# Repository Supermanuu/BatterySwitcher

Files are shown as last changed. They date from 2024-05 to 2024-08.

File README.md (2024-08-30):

# Sofle Battery Switcher




We are triying to make a battery switch for the Sofle Keyboard, or properly said, the [nRFMicro](https://github.com/joric/nrfmicro/tree/1.4) or Pro Micro compatible board used by the [Sofle](https://github.com/josefadamcik/SofleKeyboard) Keyboard.

Our goal is to have a PCB that could short and open the baterry supply via a switch, keeping as low profile as possible and doing it as integrated as possible. Also, the device should change the battery in any of the positions, because the `nRFMicro` has a battery charge monitor.

## Setup

In order to use this repo you should add a `KICAD_3RD_PARTY` variable with `${KIPRJMOD}/3rdparty/` value. If you had installed Kicad for all users, the variable shall be a system variable. Otherwise it can be a user variable.

Also, to commit the messages we use <https://github.com/marketplace/actions/github-actions-create-tag>, so your commit messages need to follow a certain format. In order to do so, you need to install some git hooks. You can do that by running the following command:

```bash
./scripts/setup-hooks.sh
```

## Used plugins

* For download parts from [Component Search Engine](https://componentsearchengine.com/): [Import-LIB-KiCad-Plugin](https://github.com/Steffen-W/Import-LIB-KiCad-Plugin)

## Documentation

See [the documentation](doc/user-guide.md).

## Releases

See [Github releases](https://github.com/Supermanuu/BatterySwitcher/releases).

Each release has:

* User guide in `user-guide.html`, with a lot of information to build the PCB.
* iBOM in `ibom.html`, with all the PCB parts.
* Another BOM in `out-of-bom.html`, with parts not used by the PCB, but needed in some cases.
* Schematic in `schematic.pdf`, with the diagram of the PCB.
* PCB images:
  * top view in `top.png`.
  * bottom view in `bottom.png`.

Another attach has:

* Gerber files and drill files in `manufacturing.zip`
* 3D model in `3D.step`

## Generate release

To generate a release you will need to create a new `release/*` branch and make a PR from that branch to main. In that scenario, when the PR is closed a job will be launched. That job will generate a tag and a release with all the change information from the previous tag until now, using the commit contents as specified in <https://github.com/marketplace/actions/github-tag>.

### Release changelog management

In order to auto-generate the changelog, the commits shall use this rules:

| Keyword | Example | Increases |
|---|---|---|
| `fix(something)`  | fix(pencil): stop graphite breaking when too much pressure applied | Patch |
| `feat(something)` | feat(pencil): add 'graphiteWidth' option | Minor |
| `perf(something)` | perf(pencil): remove graphiteWidth option | Major |

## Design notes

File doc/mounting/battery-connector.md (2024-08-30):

# Other components

This build needs a battery connector only if you have soldered the optional J1 connector only.

The materials that you  will need apart of  the BOM are described [here](../out-of-bom.md).

To mount the battery connector you should cut the wires at the appropiate length and crimp a cable terminator. First crimp the black cable:

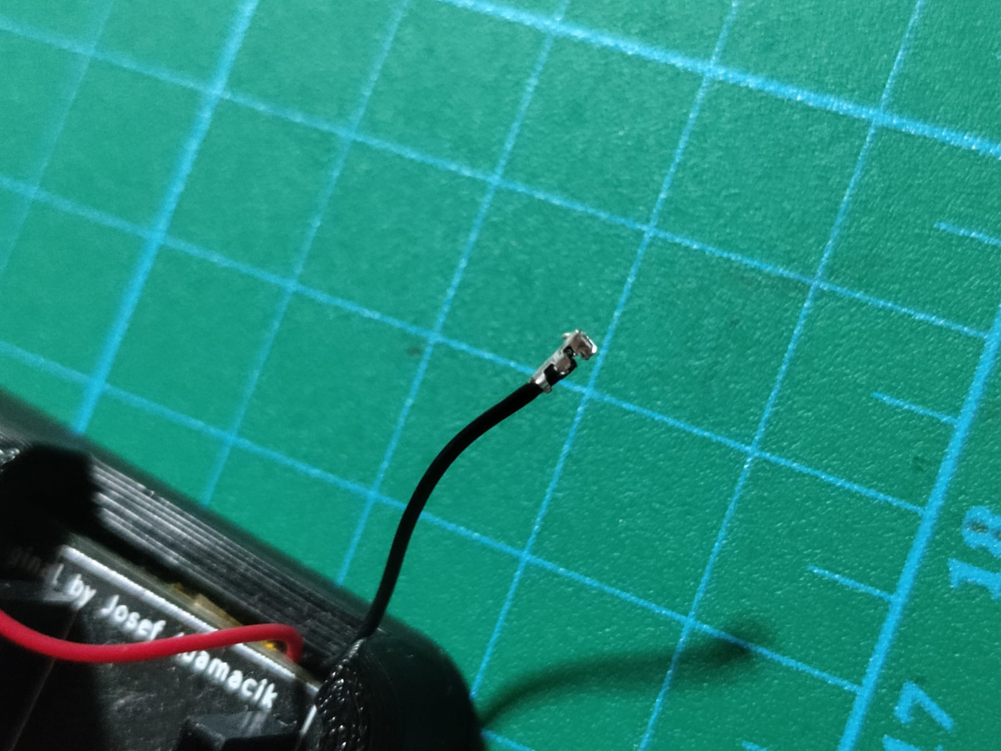
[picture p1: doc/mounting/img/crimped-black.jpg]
Black crimped


Then you should insert the terminator into the connector housing:

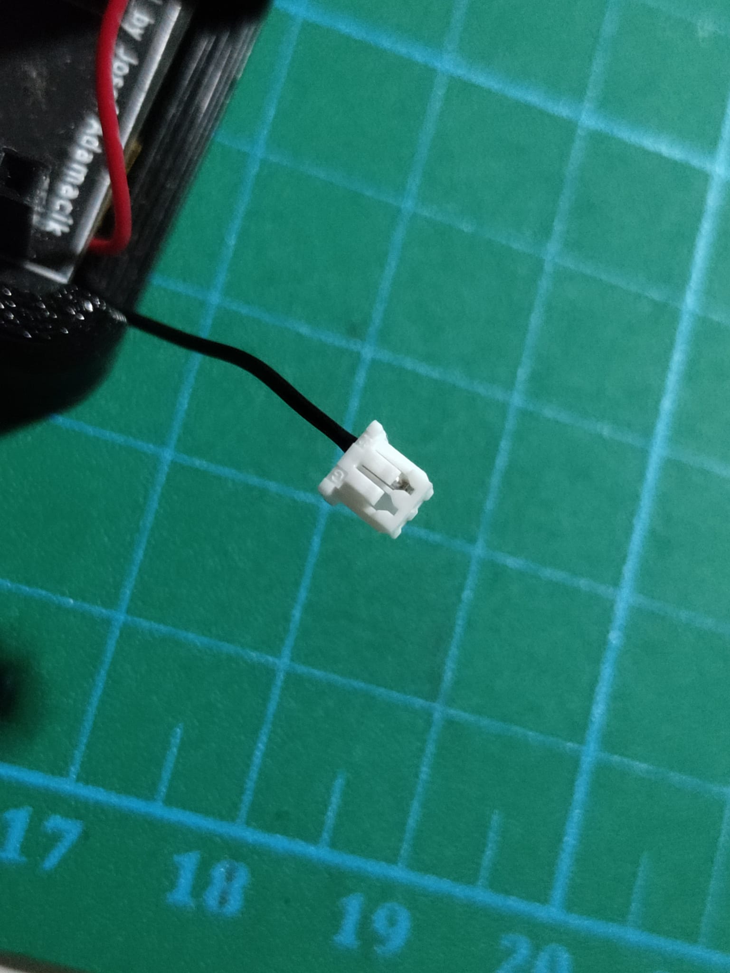
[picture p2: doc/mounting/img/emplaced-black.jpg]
Black emplaced


Now do it with the red wire:

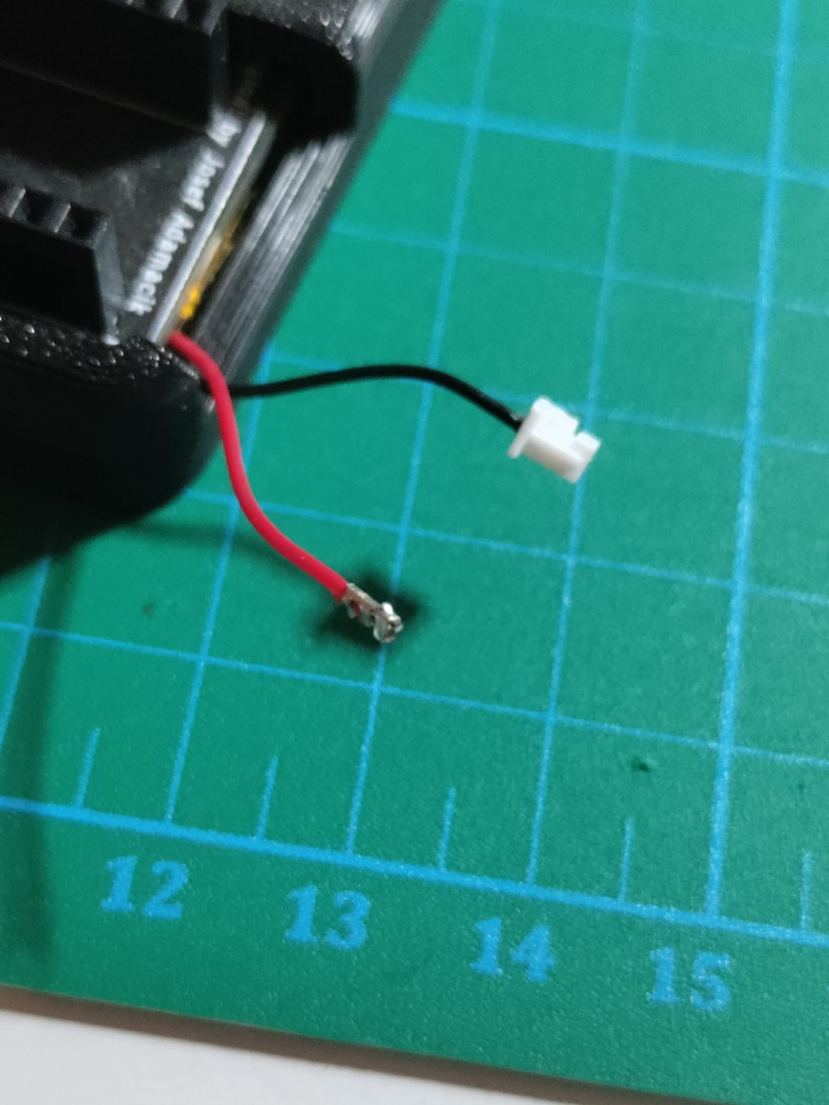
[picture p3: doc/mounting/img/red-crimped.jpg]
Red crimped


And add it to the connector:

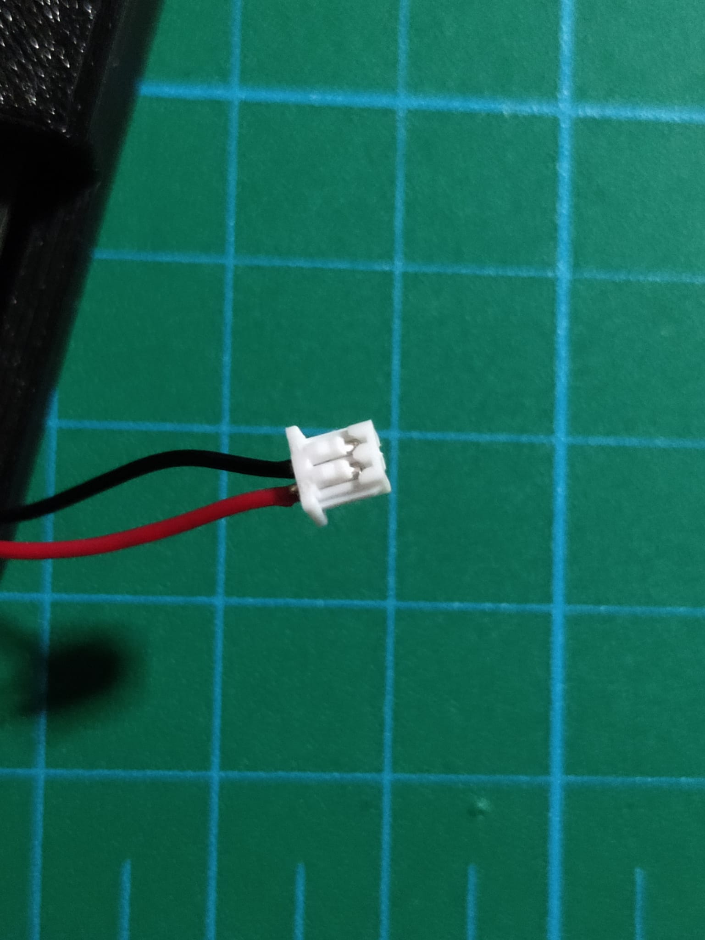
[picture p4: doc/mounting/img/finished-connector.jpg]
Finished connector


Finally you have your battery connector ready!

You can continue with the [PCB](./pcb.md).

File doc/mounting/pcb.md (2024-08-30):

# Mounting the PCB

Get the PCB and the D1:

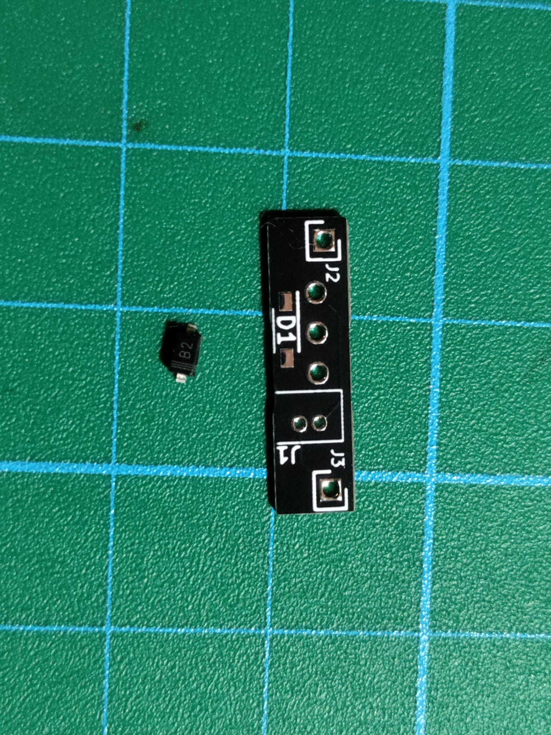
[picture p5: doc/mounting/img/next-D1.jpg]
D1


Solder the D1 component. Place the PCB on the bottom view and solder the diode paths with caution. Check the diode polarity:

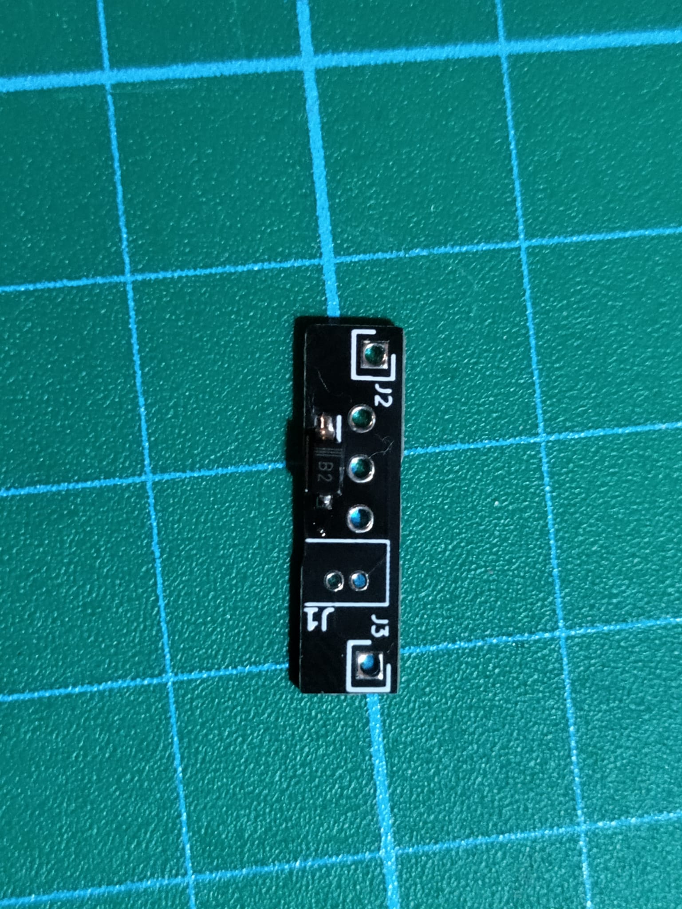
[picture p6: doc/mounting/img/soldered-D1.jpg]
Soldered D1


Get the J1 component (optional):

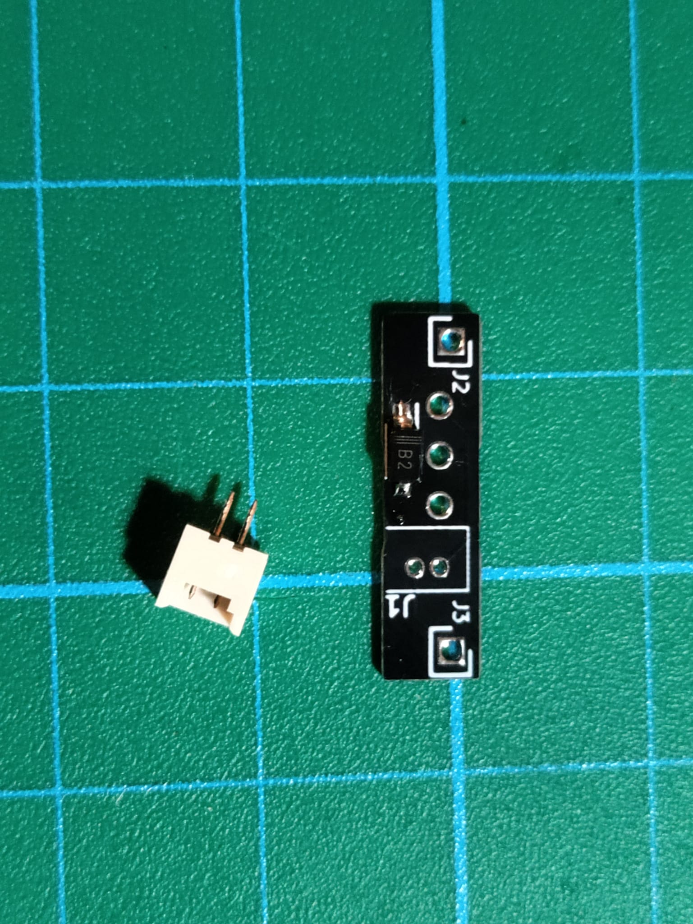
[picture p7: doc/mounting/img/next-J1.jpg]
J1


Solder the J1 component (optional). From the bottom view, solder the connector. Use tape for secure and effective placement. Place the connetor fixing plate inwards:

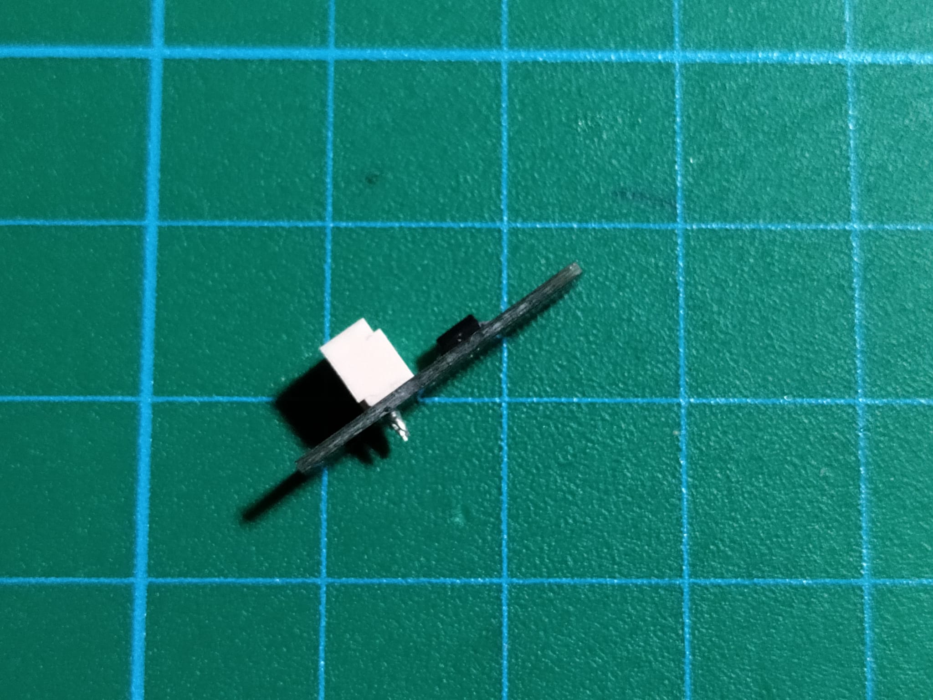
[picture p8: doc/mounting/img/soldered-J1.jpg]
Soldered J1


Get the S1 component:

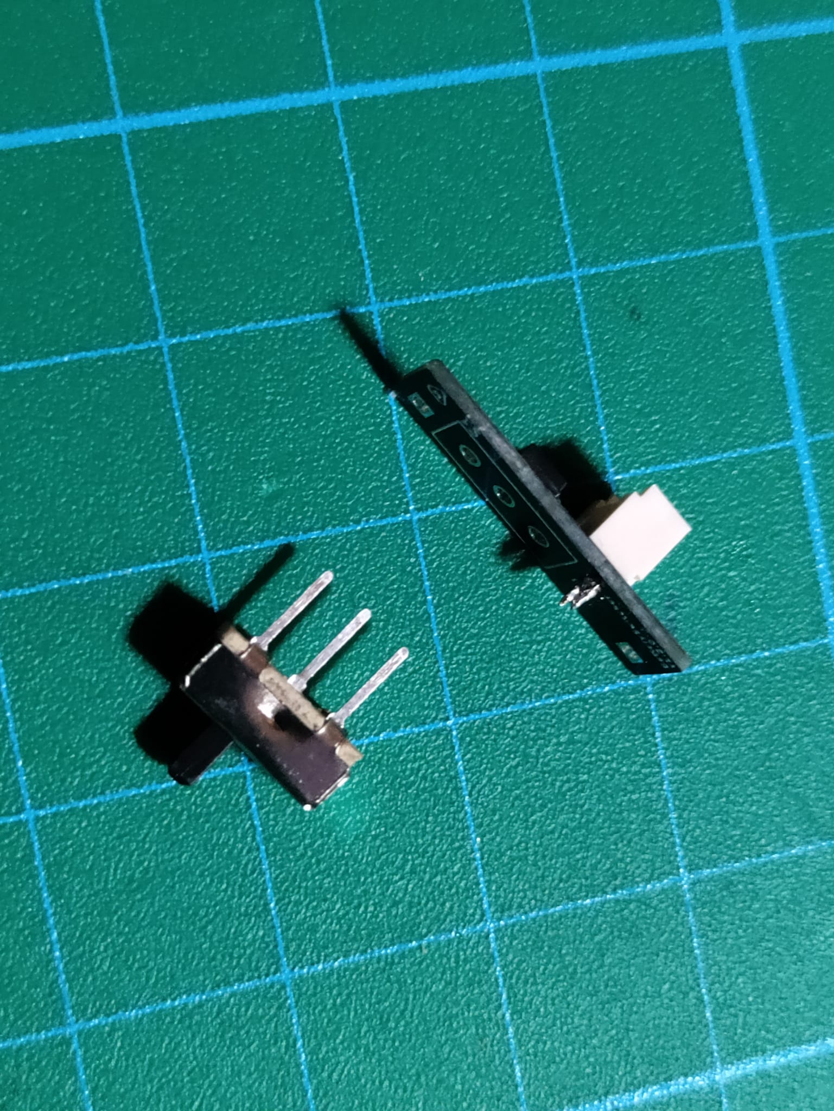
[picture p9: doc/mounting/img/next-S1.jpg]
S1


Solder the S1 component. Just solder the three pins using tape.

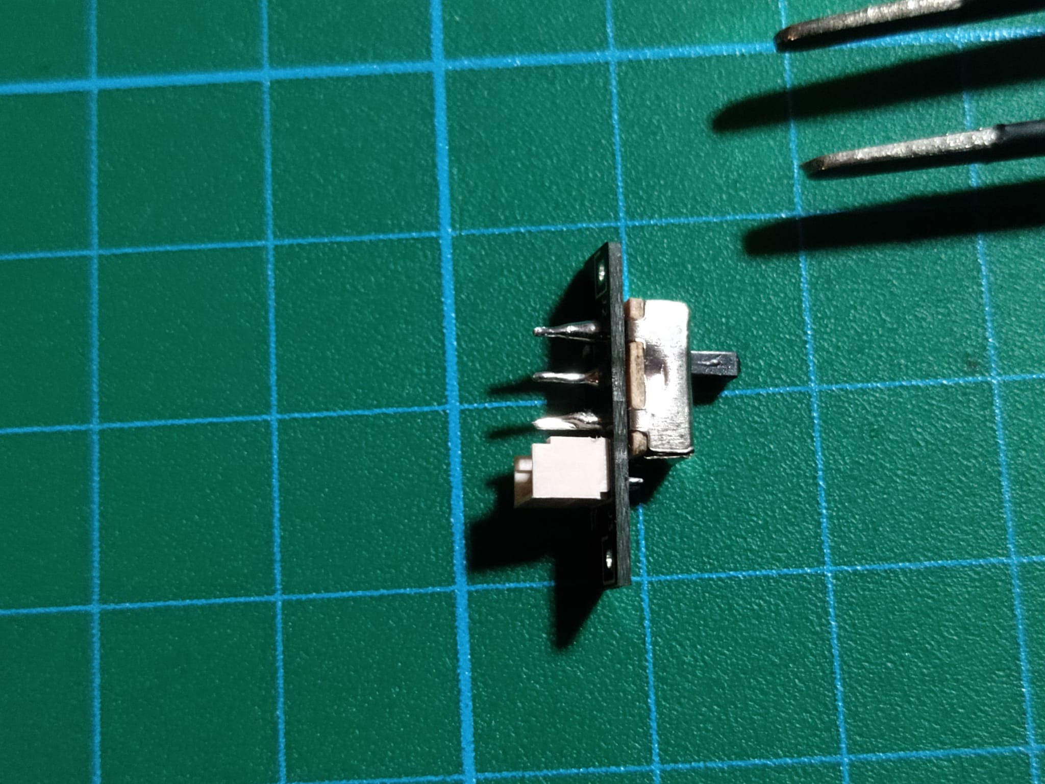
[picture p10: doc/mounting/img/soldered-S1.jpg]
Soldered S1


At this point, perform some excess trimming to avoid future problems:

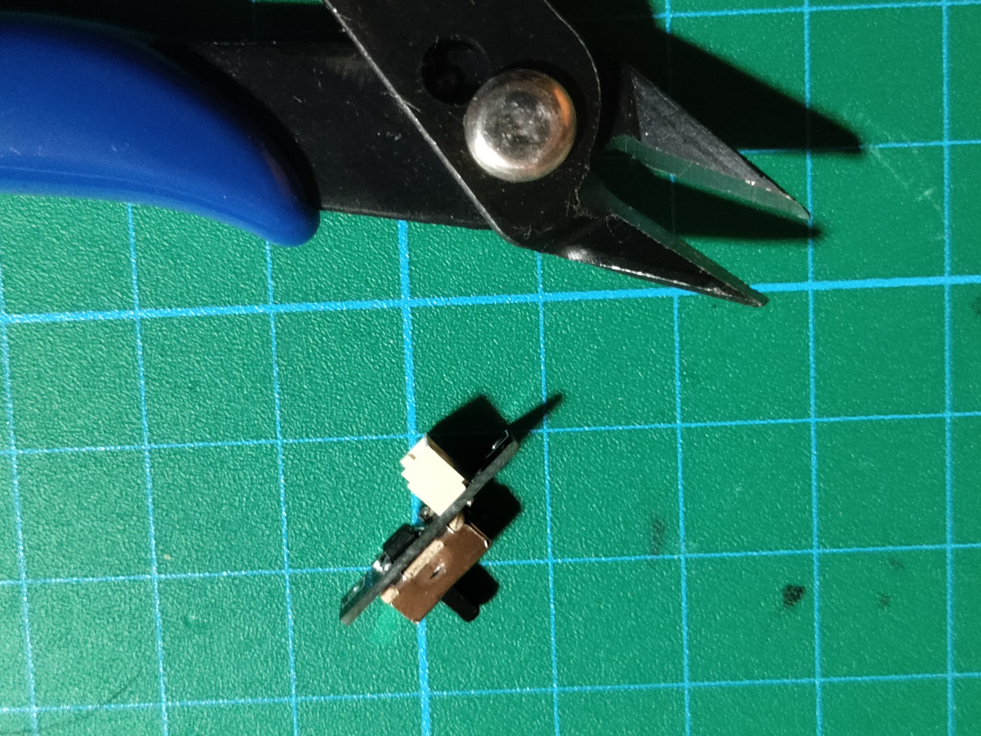
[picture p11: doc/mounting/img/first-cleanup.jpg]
Trim some excess


Follow the [battery connector](battery-connector.md) section if you have soldered the battery connector.

At this point you need to bend the PCB headers in a right angle. Split the headers and remove the retainer:

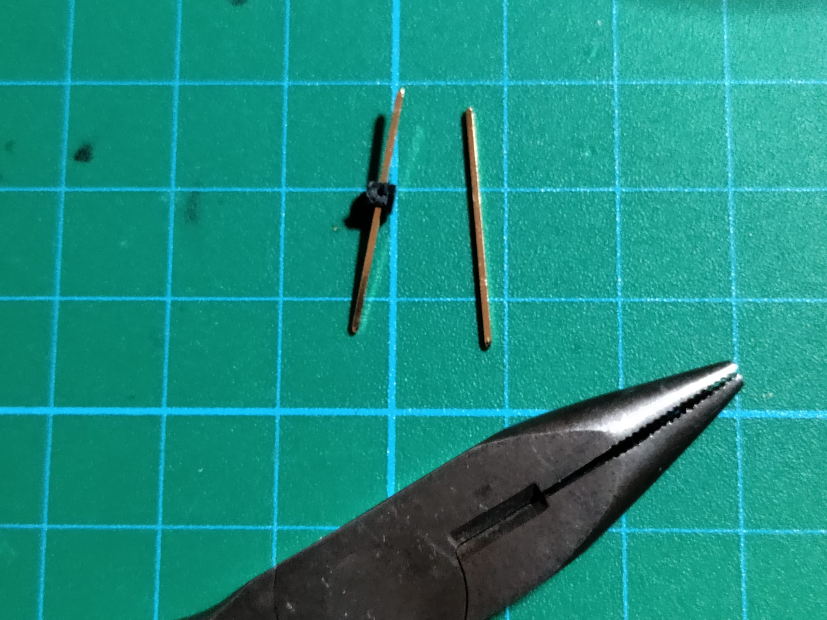
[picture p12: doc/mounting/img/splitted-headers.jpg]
Splitted headers


Then do a 90 degree bend:

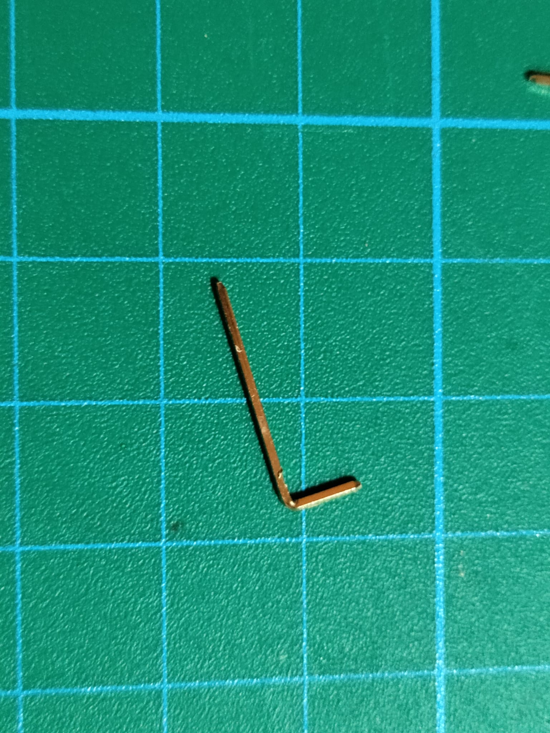
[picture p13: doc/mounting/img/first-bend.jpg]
First 90 degree angle


Then perform a 30 degree angle and another -30 degree angle:

TODO: add image

**IMPORTANT: If you want to avoid rising the switch from the keyboard base, you should not perform only 90 degree angles, try to use the minimum slope in 2nd and 3th bends. Avoid the following shape:**

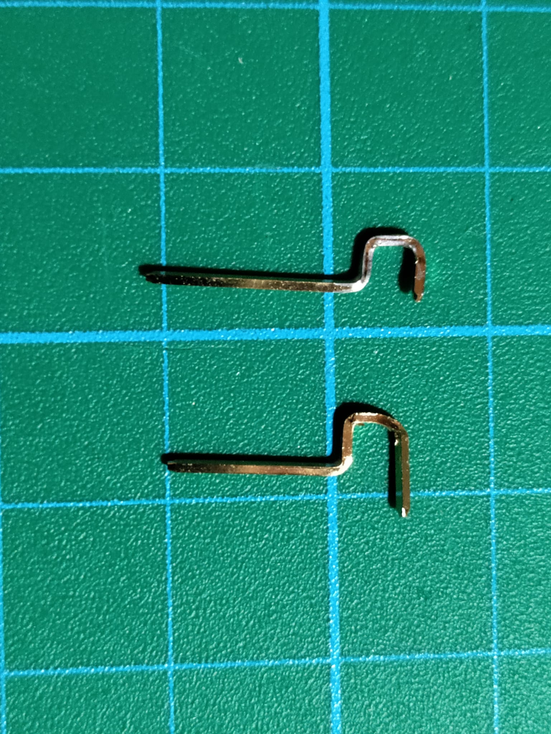
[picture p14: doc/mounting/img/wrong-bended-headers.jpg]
Wrong bending


That will be the ending shape. You will need two of the previous bended headers to be soldered into J2 and J3. First solder J2:

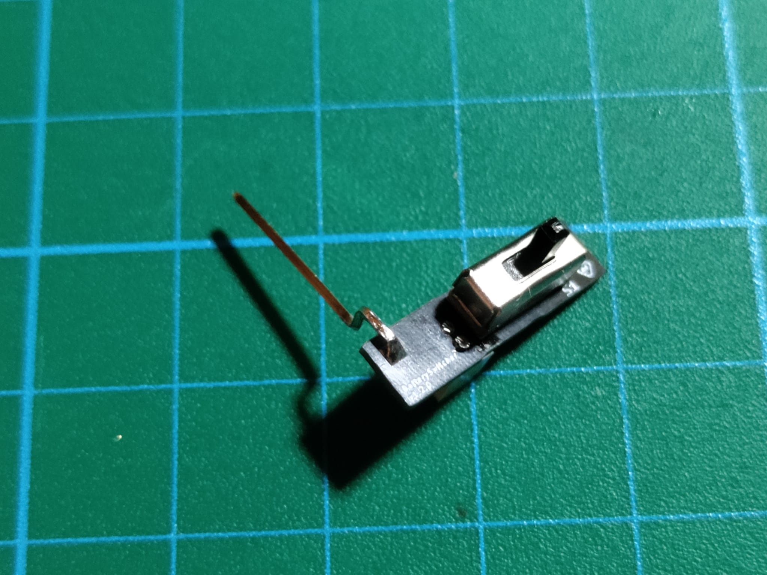
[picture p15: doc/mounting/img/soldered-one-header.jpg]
Soldered J2


Then solder J3. It will be better to solder it with the tob view at the top:

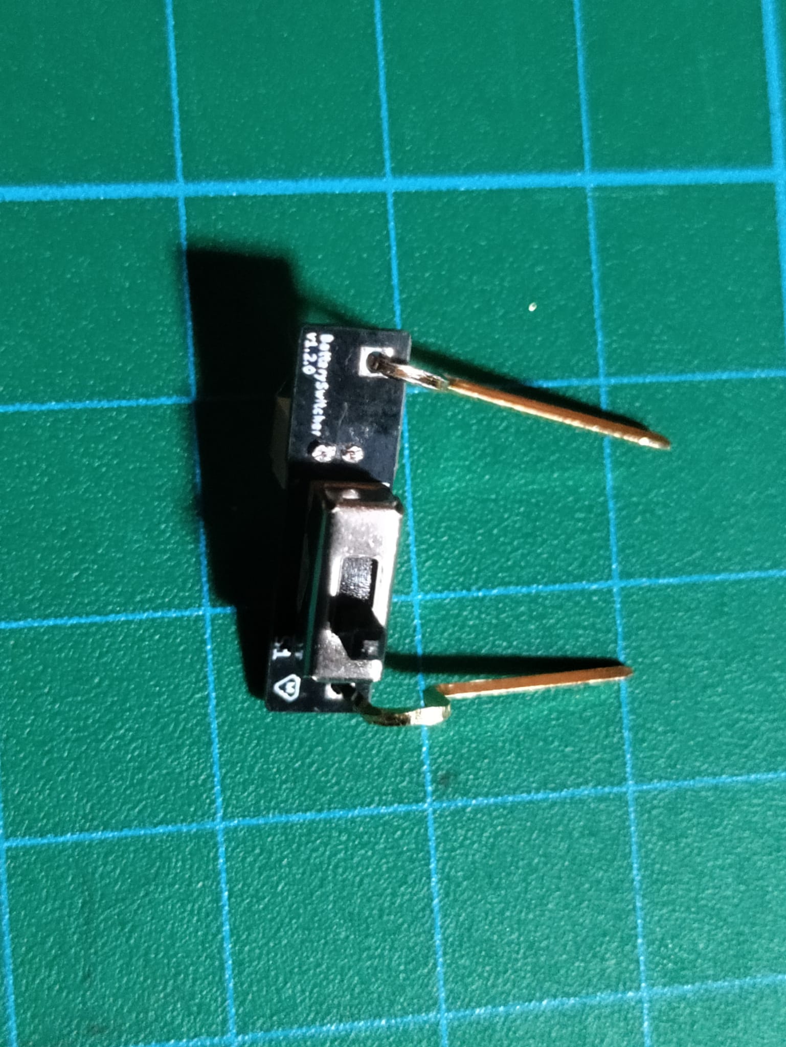
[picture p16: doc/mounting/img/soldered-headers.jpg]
Soldered J3

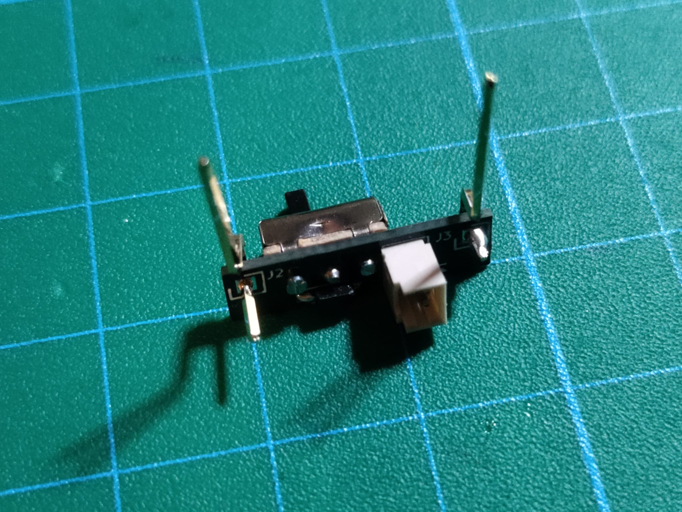
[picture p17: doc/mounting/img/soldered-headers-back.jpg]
Soldered J3 back view


Trim again the excess material:

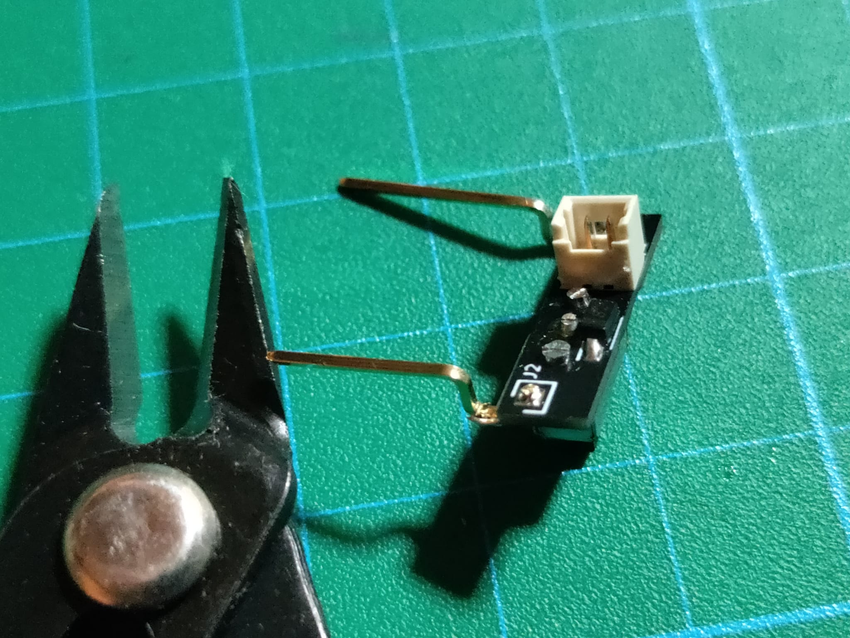
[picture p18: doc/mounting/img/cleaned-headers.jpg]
Second trimming


At this point you can solder it to the Pro Micro or compatible board:

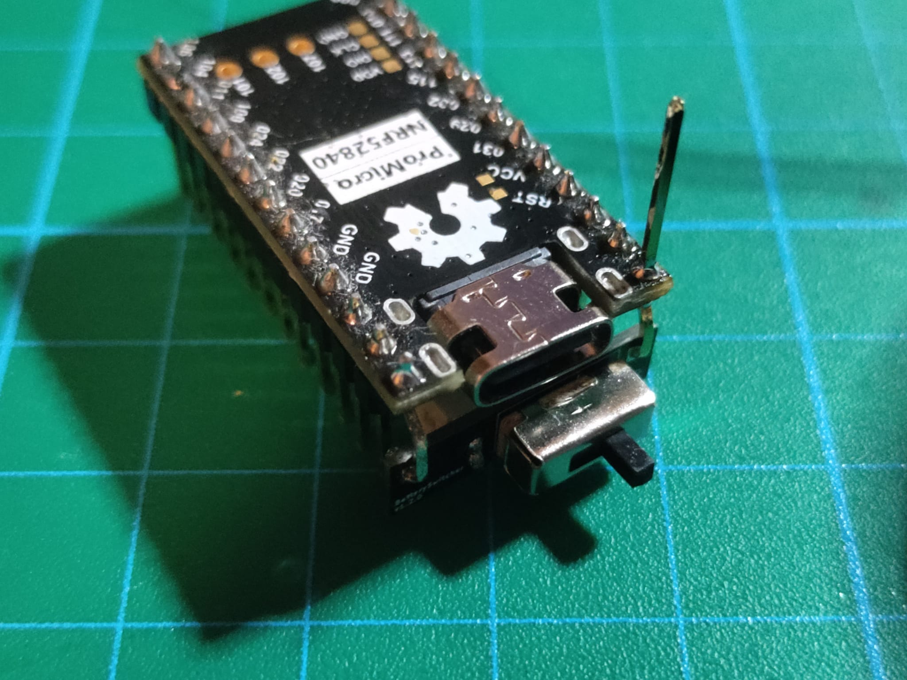
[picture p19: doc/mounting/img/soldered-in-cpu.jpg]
Soldered in CPU

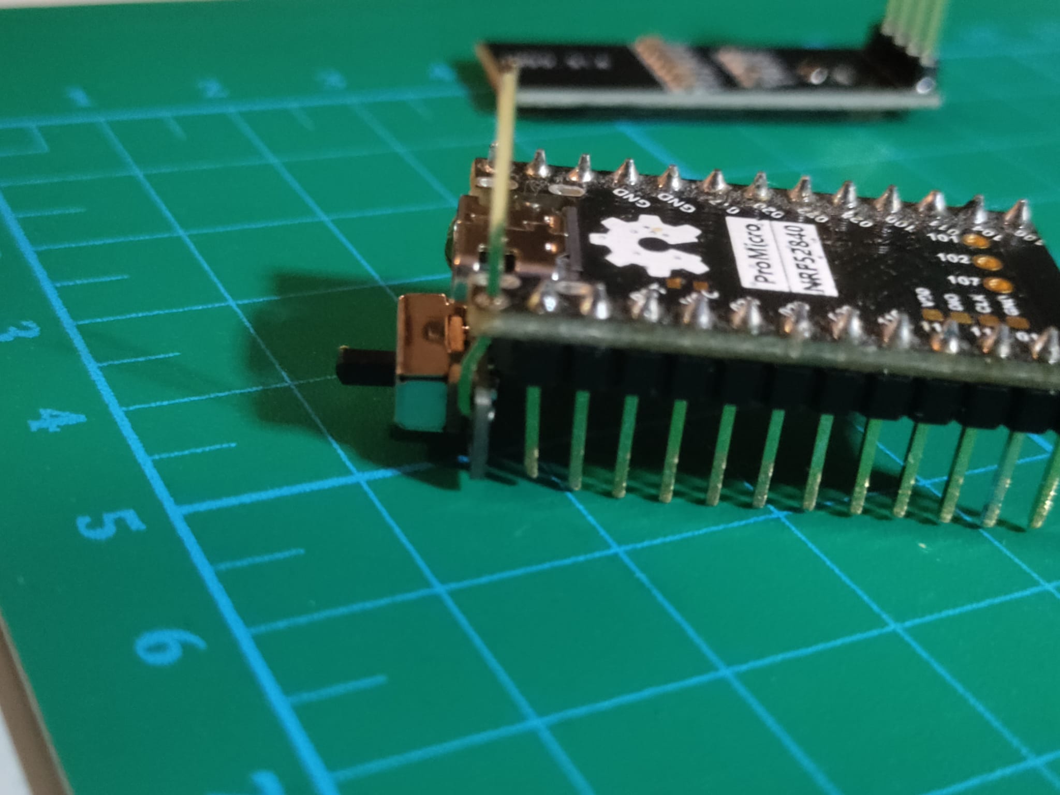
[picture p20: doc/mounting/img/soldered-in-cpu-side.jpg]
Soldered in CPU side


**IMPORTANT: Try to avoid to move the headers when are soldered because you can break a header, as it happened to me:**

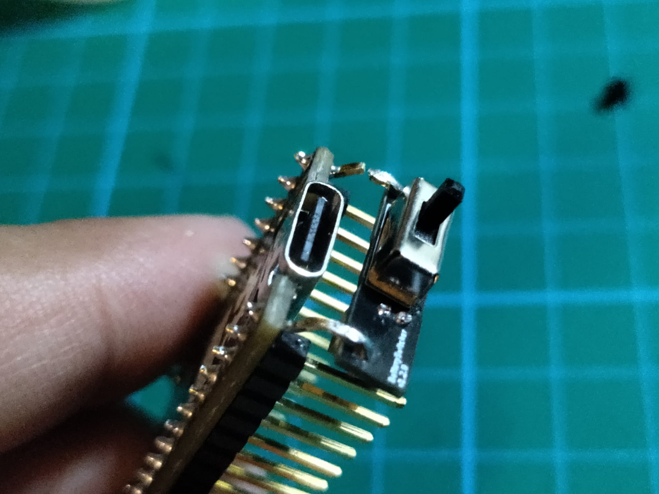
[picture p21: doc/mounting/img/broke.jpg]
Broken header


Remove again the excess and start mounting altogheder!

1. Connect the battery connector
2. Connect the Pro Micro compatible CPU to the keyboard
3. Connect the OLED displayy, if you have it.

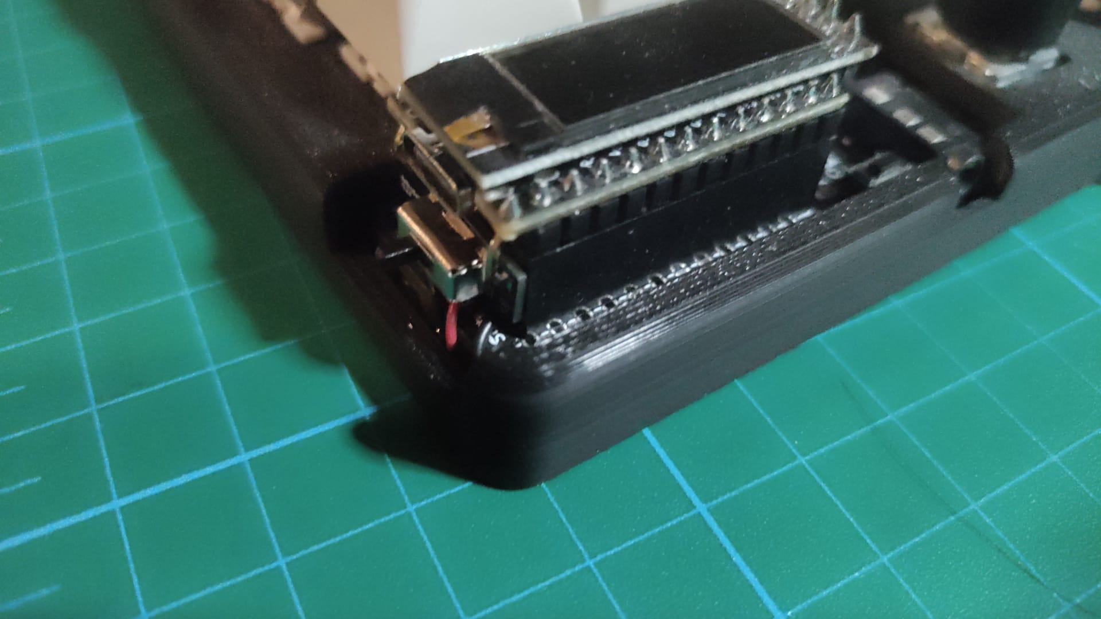
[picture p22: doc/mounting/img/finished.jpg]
Finished


Done!

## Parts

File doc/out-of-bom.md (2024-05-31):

# Non PCB parts

|#  |Qty|P/N |Purpose | Link |
|---|---|---|---|---|
| 1 | 2 | 50079-8001 | Battery connector | [Molex](https://www.molex.com/en-us/products/part-detail/500798001) |
| 2 | 1 | 51021-0200 | Battery connector | [Molex](https://www.molex.com/en-us/products/part-detail/510210200) |

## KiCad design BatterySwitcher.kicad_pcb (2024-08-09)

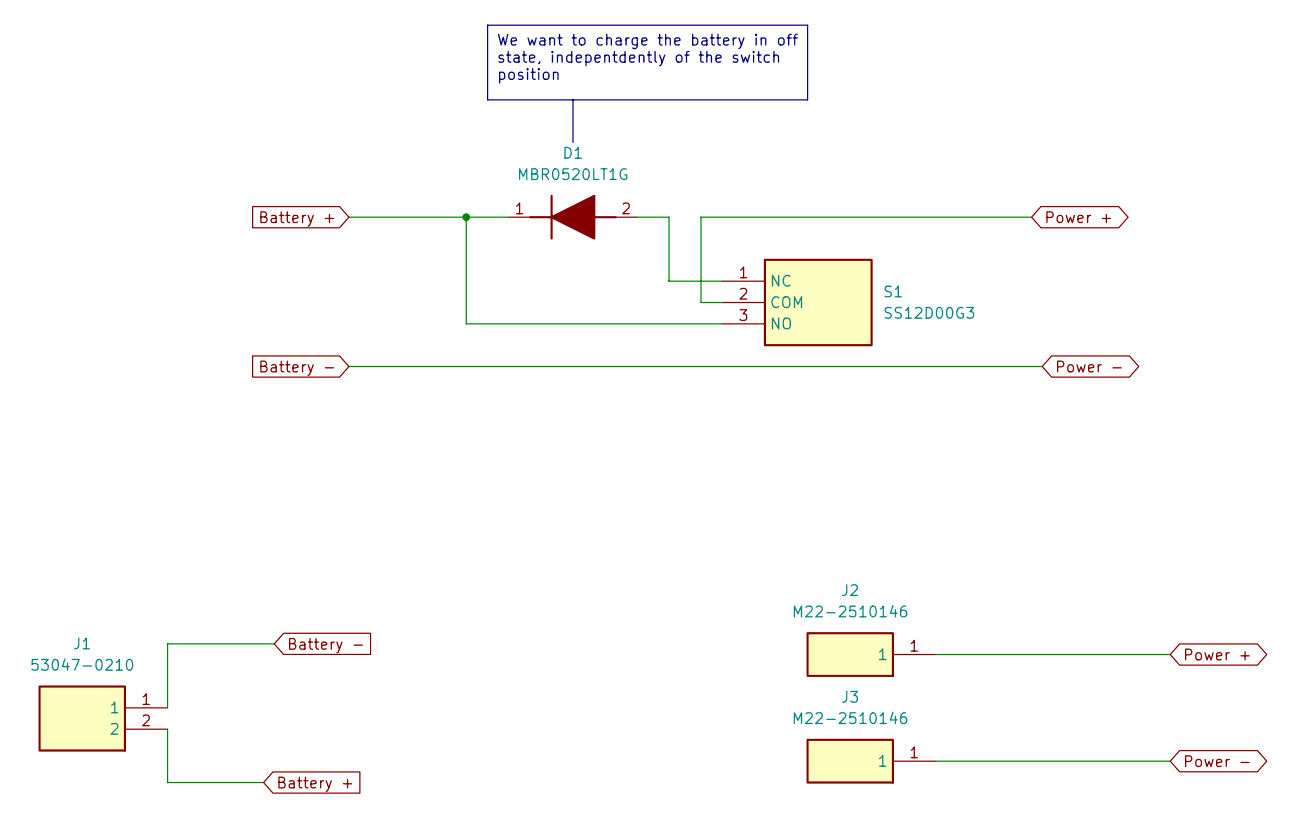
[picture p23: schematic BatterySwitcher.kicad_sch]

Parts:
D1: MBR0520LT1G; SOD3716X135N; Manufacturer_Part_Number MBR0520LT1G; Mouser Part Number 863-MBR0520LT1G
J1: 53047-0210; 530470210; Manufacturer_Part_Number 53047-0210; Mouser Part Number 538-53047-0210
J2, J3: M22-2510146; HDRV1W50P0X200_1X1_200X200X525P; Manufacturer_Part_Number M22-2510146; Mouser Part Number 855-M22-2510146
S1: SS12D00G3; Manufacturer_Part_Number SS12D00G3

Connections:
Battery +: D1.1 (K), J1.2, S1.3 (NO)
Battery -: J1.1, J3.1
unnamed: D1.2 (A), S1.1 (NC)
Power +: J2.1, S1.2 (COM)

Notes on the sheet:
We want to charge the battery in off state, indepentdently of the switch position

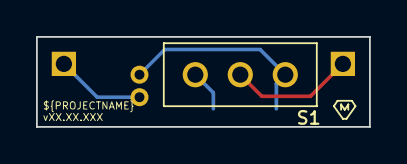
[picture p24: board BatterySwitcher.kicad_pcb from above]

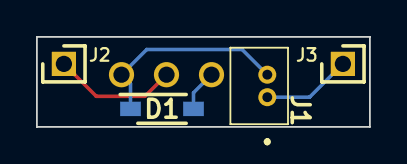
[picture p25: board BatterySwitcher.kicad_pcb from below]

Board: 2 copper layers, 18.5 x 5.0 mm, 5 parts (4 on the bottom side), 4 nets.

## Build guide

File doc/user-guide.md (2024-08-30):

# User guide

This user guide will be your ally for mounting the BatterySwitcher!

Top view (only works from artifact documentation)
Tottom view (only works from artifact documentation)

In  this files you will have a lot of information for building this project:

* [iBOM](ibom.html)
* [Schematic (only works from artifact documentation)](schematic.pdf)

Buy all the components in the [iBOM](ibom.html) and the ones gathered in [Out of BOM](out-of-bom.md) from whatever supplier you like and then, start [building](mounting/pcb.md).

---





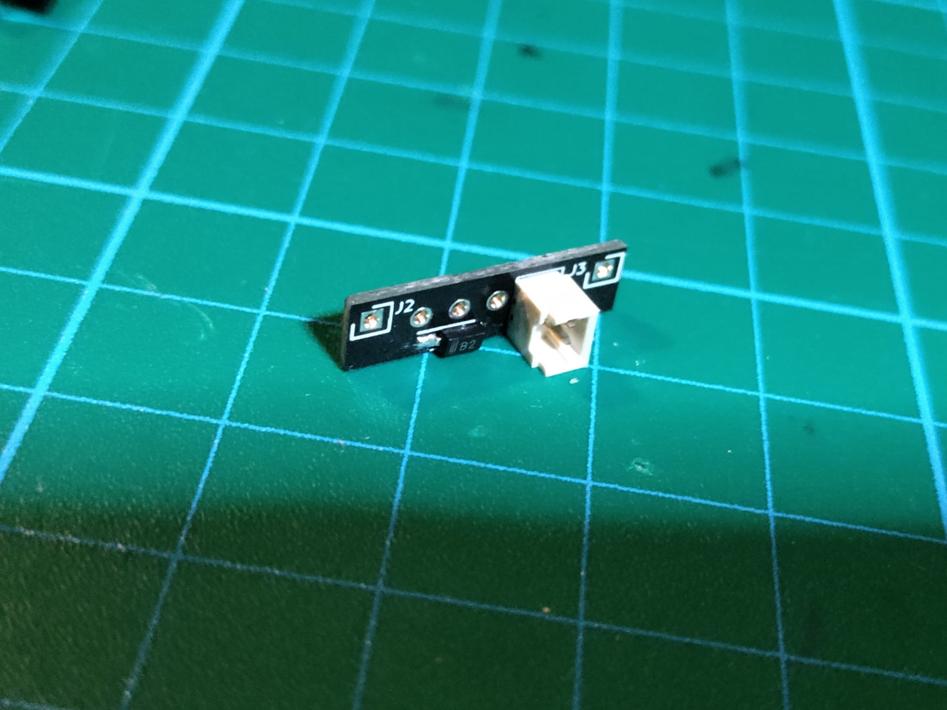
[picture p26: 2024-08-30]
doc/mounting/img/soldered-S1-front.jpg

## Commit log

2024-05-19 only dip pins left
    [BatterySwitcher.kicad_pcb, BatterySwitcher.kicad_sch]
2024-05-19 using official gitignore
    [BatterySwitcher.kicad_pcb, BatterySwitcher.kicad_sch]
2024-05-19 added dip pins for battery and power connections and routing done
    [BatterySwitcher.kicad_pcb, BatterySwitcher.kicad_sch]
2024-05-20 acciones de la revision de la placa
2024-05-20 fixed some issues noticed from Miguel Angel
    Removed ground plane
    Checked copper width for 500mA
    Changed diode to shottky with less forward voltage
    Added battery connector
    Rearrange header pins to be from behind
    Reroute all
    Added pcb measures
    Added part number
    Added my signature
    Added bill of materials
    [BatterySwitcher.kicad_pcb, BatterySwitcher.kicad_sch]
2024-05-21 real spacing requirements
    [BatterySwitcher.kicad_pcb]
2024-05-21 changed switch by a shorter one
    achieved minimum footprint
    [BatterySwitcher.kicad_pcb, BatterySwitcher.kicad_sch]
2024-05-22 using 3rd party from repo
    [BatterySwitcher.kicad_pcb]
2024-05-22 fixed header pins polarity
    [BatterySwitcher.kicad_pcb]
2024-05-27 changed arrange to 5mm
    [BatterySwitcher.kicad_pcb]
2024-05-27 fixed J3 silkscreen cut
    [BatterySwitcher.kicad_pcb]
2024-05-27 added readme and changed severity of courtyards_overlap
    [BatterySwitcher.kicad_pcb]
2024-05-28 Actualizar gerber.yml
2024-05-28 fixed gerber.yml
2024-05-31 removed normal bom
2024-05-31 finished development
    [BatterySwitcher.kicad_pcb, BatterySwitcher.kicad_sch]
2024-05-31 fixed 2 drc silkscreen
    [BatterySwitcher.kicad_pcb]
2024-06-23 fixed bad headers
    Now headers are 0.5 square
    PCB size increased in 1mm length, wide remains the same
    Rotated J1 due spacing
    Rerouted PCB
    [BatterySwitcher.kicad_pcb, BatterySwitcher.kicad_sch]
2024-06-23 new idea: put behind hte battery connector
2024-06-25 added KICAD_3RD_PARTY environment variable
2024-06-25 removed consolas font
    [BatterySwitcher.kicad_pcb]
2024-07-05 added real board
2024-07-31 added git version
    [BatterySwitcher.kicad_pcb]
2024-07-31 improved version replacement placeholder
    [BatterySwitcher.kicad_pcb]
2024-07-31 fixed J2 and J3 placement
    [BatterySwitcher.kicad_pcb]
2024-08-02 changed battery connector to be placed on the back
    [BatterySwitcher.kicad_pcb]
2024-08-02 added shematic git versioning
    [BatterySwitcher.kicad_sch]
2024-08-09 fix(publish release): using mathieudutour/github-tag-action in release.yml
    Now the tag info is retrieved by a dry run of the mathieudutour/github-tag-action that not creates any tag in the end term
    The version placeholder has been shorten too
    [BatterySwitcher.kicad_pcb, BatterySwitcher.kicad_sch]
2024-08-30 N/A: reviewed mounting manual
2024-08-30 feat(updated documentation): added detailed mounting manual
